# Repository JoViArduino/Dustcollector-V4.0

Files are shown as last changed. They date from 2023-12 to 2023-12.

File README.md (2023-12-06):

# Arduino Project: Dustcollector version 4 

Controlling dustcollecting system for multiple machines using valves. 

<p align="left" width="100%">
  
 

For every woodworker using lot of stationary machines it is important to remove the dust which is produced by using these machines. When one has many different machines, like table-saw, planer of a thicknesser one needs to connect all these machines. One needs to connect al these machies and includes valves so that only the dust of the machine which is used is collected. To achieve this one needs to include valves. This project allows you to install automatied valves which are controlled by Arduino''s. There is one Arduino for each manche. On them one and the same program can be installed. 
</p>


<br>
<sup> 
(The PCB for the project. An Arduino Uno is mounted under it while above there is an RS485 module. Here the PCB is placed on a test print of housing. Note the housing is only printer partially here, to see whether the PCB fits.)
</sup>

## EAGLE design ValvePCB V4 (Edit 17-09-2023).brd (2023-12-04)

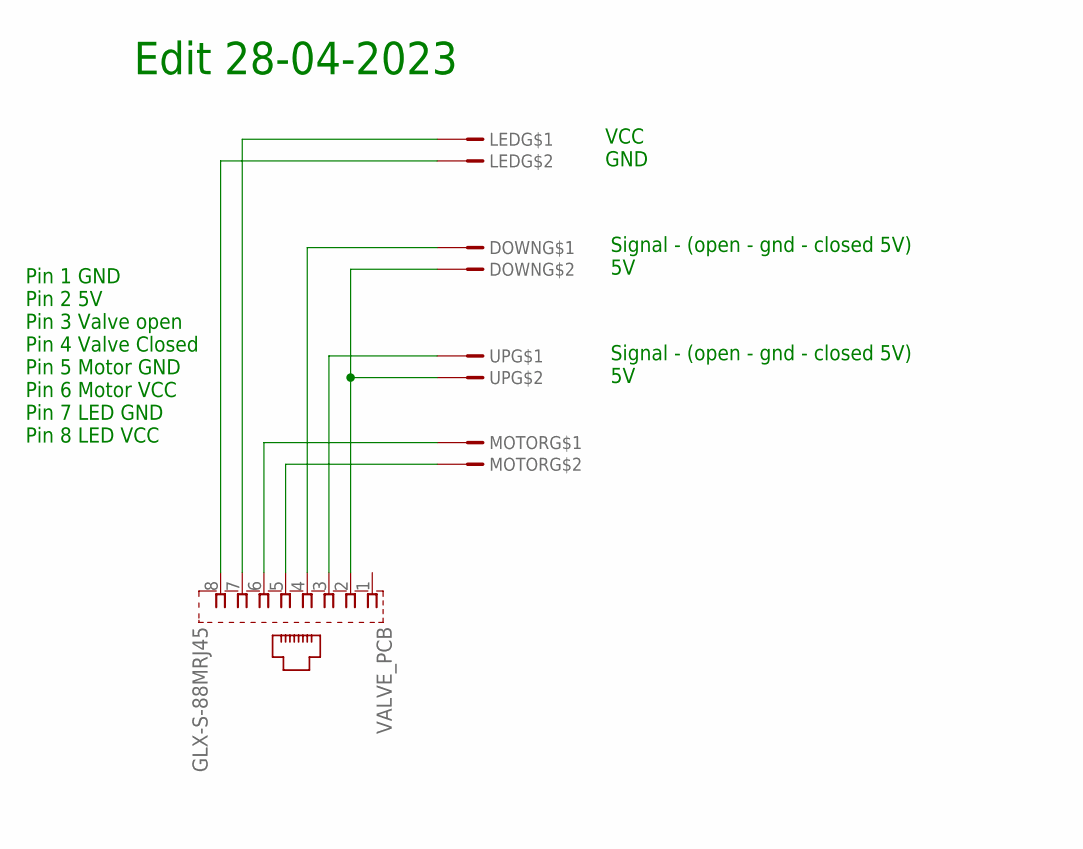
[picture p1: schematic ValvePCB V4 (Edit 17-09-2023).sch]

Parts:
DOWN: JST2; HDRV2W64P254_1X2_712X508X838B
LED: JST2; HDRV2W64P254_1X2_712X508X838B
MOTOR: JST2; HDRV2W64P254_1X2_712X508X838B
UP: JST2; HDRV2W64P254_1X2_712X508X838B
VALVE_PCB: GLX-S-88MRJ45; GLX-S-88M

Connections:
unnamed: MOTOR.1, VALVE_PCB.6
unnamed: MOTOR.2, VALVE_PCB.5
unnamed: UP.1, VALVE_PCB.3
unnamed: DOWN.2, UP.2, VALVE_PCB.2
unnamed: DOWN.1, VALVE_PCB.4
unnamed: LED.2, VALVE_PCB.8
unnamed: LED.1, VALVE_PCB.7

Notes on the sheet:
Pin 1 GND Pin 2 5V Pin 3 Valve open Pin 4 Valve Closed Pin 5 Motor GND Pin 6 Motor VCC Pin 7 LED GND Pin 8 LED VCC
Edit 28-04-2023
Signal - (open - gnd - closed 5V) 5V
VCC GND

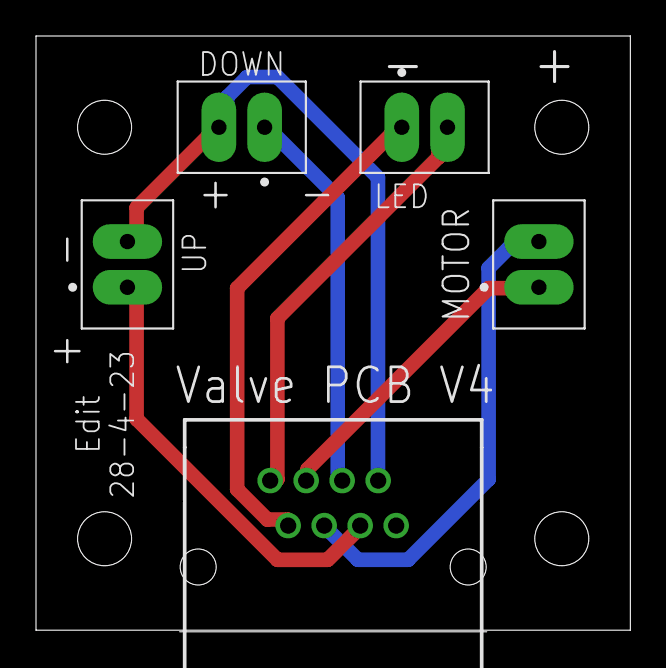
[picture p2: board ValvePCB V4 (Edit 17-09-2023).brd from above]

Board: 2 copper layers, 33.0 x 33.0 mm, 5 parts (0 on the bottom side), 7 nets.

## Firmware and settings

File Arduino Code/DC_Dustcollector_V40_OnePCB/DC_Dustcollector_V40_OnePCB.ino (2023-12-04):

//---------------------------------------------------------------------------------------------
// Dustcollector V4.0
//---------------------------------------------------------------------------------------------
//
// WARNING!!!!!!!!!!!!!!!!!!
// THIS VERSION is for dustcollector using one PCB....
// it cannot be used on the older version, which uses different pcb's... pinout is different!!!
// They are however compatible!!!!! ---> V3.1 25-11-2023!!!!
//
//---------------------------------------------------------------------------------------------
//
// Name......: DC_Dustcollector_V32_OnePCB.ino
//
// Version...: V3.1 - 28-06-2023
// last edits: 14-02-2023
//           : 28-04-2023
//           : 17-05-2023 introducing tabs!!
//           : 21-05-2023 resistor pulling Emergency low...
//           : 26-05-2023 Made some minor changes...
//           : 31-05-2023 Again some minor changes....
//           : 07-06-2023 Debugged DC Delay after restart and
//                        fixed bugs....
//           : 08-06-2023 Added response for Version All command!!
//           : 28-06-2023 Cleaning code .... minor fixes...
//           : 19-09-2023 Implementing functions for machines!!!
//           : 29-11-2023 Adjust functions to be used with one PCB
//                        and posility to reset all Arduino's remotly!!
// Author....: J. Vink
// Board.....: Arduino Uno
//
//---------------------------------------------------------------------------------------------
//
// See for description the Word document!! There is only one program for all Arduino's!!!!
//
//---------------------------------------------------------------------------------------------
//
// Changelog 20-04-2023
//
// Almost out of memory for variables (dynamic memory) ... so now using F( "...." ) within
// Sertial.print commands. This will store the text in the program storage space. Saved
// almost 30% ..............
//
// Changelog 28-04-2023:
//
// Discovered fault in the controller PCB. The three resistors are not connected to GND, ass they
// should be. Instead they are connected to the 5V line. So, when buttons are not pushed, the
// remain HIGH / 5V. The same holds for the resistors for the valves. They are also connected
// to %V instead of GND line.
//
// The PCB have been corrected and title have been given extra name (Edit 28-04-2023)!! These
// pcb's are ordered and this project assumes that these corrected pcb's will be used.
//
// Received PCB's from PCBWay ... so removed workarounds !!!!
//
// Changelog 21-05-2023:
//
// The Emergency line needs to bee pulled to GND. Otherwise it will float and randomly trigger
// emergency events. The Resister, 10K, needs to be soldered on one of the Arduino's. This
// will be the Arduino of the Dustcollector, as this one is always on. PCB for the
// controllers has been altered, so that a 10k resistor can be placed there, but for now
// it will be soldered on the Arduono of the Dustcollector!!!
//
// Tested this new settup .... does not work!!
//
// Changed Emergency pin from 13 to A3: This because this pin is connected to the onboard
// LED. Pulling the pin to ground therefore doesn not work!!
//
// New Pin A4 can be pulled low by 10k resistor. Pnly only one is needed... Added it
// to the Dustcollector controller!!
//
// Changelog 26-05-2023
//
// When installing the system discovered that for a stationary machines there was the need
// for an extra button. This button is connected to the handle with which the machine is
// operated. However all the lines are used. How to solve this problem?
//
// Solution: Use a separated box in which a Relais is switched using a deadman button
// (driven by 5V). This solves the need for another change to the PCB and leaves intact
// the possiblity of using a LEd for the power (not used at this moment).
//
// Changelog 31-05-2023
//
// Added functionality: All valves open of closed using serial. And when one valve is opened
// all others are closed. When one machine is turned of others are turned of.
//
// Changelog 03-06-2023
//
// Added the possibility to read the versions of all the connected controllers from the
// main controler!!
//
// Changelog 26-6-2023
//
// Cleaning the code....... etc etc etc.
//
// Changelog 19-9-2023
//
// Added functions for the machines / controller... some machines have build in switches
// so when these are used, we dont need a double function for the buttons in this project.
//
// Also change the check for the valves.. now first check is done after delay of 100ms!
//
//---------------------------------------------------------------------------------------------

#include <SPI.h>
#include <SoftwareSerial.h>
#include <EEPROM.h>

//---------------------------------------------------------------------------------------------
// When using serial monitor the version can be retrieved (command : Version). See below!
// This version is compatible with the latest veriosn ov V3.1, RESET is not available!!!
//---------------------------------------------------------------------------------------------

const String sVersion = "Version: V4.0 - 04-12-2023 (One PCB). ";

//------------------------------------------------------------------------------------------
// Pin defines: Note: Pins 0 and 1 not used because of usage of serial comms!!
//---------------------------------------------------------------------------------------------

#define EMERGENCY_Button_Pin  2 // Internal Emergency Button - 

//------------------------------------------
// Pins controling the communication
// between the Arduino's using the
// RS485 connection.
//------------------------------------------

#define TX_485_Pin            3 // Pin DI for the RS 485
#define RX_485_Pin            4 // Pin RO for the RS 485
#define RS485_control_Pin     5 // Pin DE / RE Enables or disables transmission and reception

#define Air_Button_BLUE_Pin   6
#define Air_Button_RED_Pin    7

//------------------------------------------
// Pins for controling relais for the valve.
// There are four relais used to control the
// polaritiy of the motor, in order rotate
// it clockwise or anticlockwise = moving
// the valve in a open or closed position.
//
// On the old many pcb version pin was this:
//
// #define Valve_Open1_Pin       8
// #define Valve_Open2_Pin       9
// #define Valve_Close1_Pin     10
// #define Valve_Close2_Pin     11
//------------------------------------------

#define Valve_Open_Pin        8
#define Valve_Close_Pin       9
#define Valve_Enabled_Pin    10

//------------------------------------------
// Pins for external emergency.
//------------------------------------------

#define RESET_Arduinos_Pin   11 // Reset all other Arduino's.

//------------------------------------------
// Pins for external emergency.
//------------------------------------------

#define EMERGENCY_Ext_Pin    12 // This is the line to the other Arduino's!!!

// Pins for the LED's.
#define LED_Motor_On_Pin     A0 // LED showing whether machine is on or off. 
#define LED_Air_On_Pin       A1 // LED showing whether dustcollector is on or off.
#define LED_Power_On_Pin     A2 // LED showing whether power is on or off (kind off stupid).

//------------------------------------------
// Pin for the Relais controling the machine.
// Using this pin as the old pin at start-up
// turned high, put on on the 220V line....
// Originaly this was pin 13. Pin 13 is connected
// to onboard LED, and will therefore will go
// into LOW state at start up, closing the
// relais and therefore start the motor.
// This problem will not occur with Analog
// pins...  so.... well....
//------------------------------------------

#define Machine_Power_Pin    A3 // Pin voor 220v relais controling power of motor!!

//------------------------------------------
// Pins for the contact switches of the airvalve.
//------------------------------------------

#define Valve_Status_Open    A4 // HIGH if switch is closed (it is NO = normally LOW)
#define Valve_Status_Closed  A5 // HIGh if switch is closed (it is NO = normally LOW)

//---------------------------------------------------------------------------------------------

#define RS485transmit HIGH
#define RS485receive  LOW

//------------------------------------------
// initiate the serial comm between the arduino's.
// This uses an external RX485 chip. THese
// can be used over longer distances.
//------------------------------------------

SoftwareSerial RS485_serial (RX_485_Pin , TX_485_Pin );

// Valve is controled by four relais. See above!!!
#define Valve_Relais_Moving  LOW    // Relais moving - current to valve, low opening, high closing
#define Valve_Relais_Idle    HIGH   // Relais idle - NO current to valve motor

#define Machine_Relais_Closed 1024  // Analog pin set to its maximum value.
#define Machine_Relais_Open   0     // Analog pin set to its lowest value.

// When emergency is raised, system requires reset...
boolean bEmergency_Raised            = false;
boolean bLeds_Emergency_On           = false;

boolean bShowDebugInfo               = false;

boolean bDust_Collector_Power_Status = false;
boolean bDustCollector_Power_On      = false;
boolean bDust_Collector_Restarting   = false;
boolean bMachine_Power_On            = false;

//------------------------------------------
// Delay for restarting the dustcollector
// Set this to 10000 = 12 seconds (appr).
//------------------------------------------

int iDust_Collecter_Restart_Counter = -1;
int iDust_Collecter_Restart_Delay_In_MilliSeconds = 10000;

//------------------------------------------
// If the valve is bissy (moving) we need
// to check whether it has reached one of
// its postions then stop the motor ASAP.
//------------------------------------------

boolean bValve_Relais_Bissy         = false;

//------------------------------------------
// If Valve is moving, then this is used for the
// direction! Opening = true, Closing = false.
//------------------------------------------

boolean bValve_Relais_Opening       = false;

//------------------------------------------
// Actions - (commands and responses)
// These are transmitted via the RS485 line.
//------------------------------------------

int iAction_Dust_Collector_On       = 1;
int iAction_Dust_Collector_Off      = 2;

int iAction_Machine_On              = 11;
int iAction_Machine_Off             = 12;

int iAction_Machine_All_Off         = 13;
int iAction_Machine_All_Others_Off  = 14;

int iAction_Status_Machine_On       = 15;
int iAction_Status_Machine_Off      = 16;

int iAction_Gate_Valve_Open_All     = 21;
int iAction_Gate_Valve_Close_All    = 22;
int iAction_Gate_Valve_Open_Others  = 23;
int iAction_Gate_Valve_Close_Others = 24;

int iAction_Request_ValveStatus     = 31;
int iAction_Status_ValveOpen        = 32;
int iAction_Status_ValveClosed      = 33;
int iAction_Status_ValveMoving      = 34;

int iAction_Project_Get_Version     = 41;
int iAction_Project_Version_Info    = 42;

int iAction_Request_Status          = 81;
int iAction_Status_Ready            = 82;

int iAction_Set_IDNumber            = 83;
int iAction_Set_MaxMachines         = 84;

int iAction_IDNumber_SetOk          = 85;
int iAction_MaxMachines_SetOk       = 86;

int iAction_IDNumber_SetFailed      = 87;
int iAction_MaxMachines_SetFailed   = 88;

int iAction_Emergency_Off           = 90;
int iAction_Emergency               = 99;

//------------------------------------------
// Controller variables stored in EEPROM
//
// There is another variable which can be
// stored in EEPROM memory See Above!!!
//
// WARNING: Dustcollector ID_Number must
// be 1 and equal to iID_DustCollector!!!
//------------------------------------------

int iID_DustCollector = 1; // Dont edit this number!!!

int iID_Number   = 99;     // It can be changed using Serial monitor - IDNumber x (where 0 < x < 64)!
// here 99 is used for a standard. If the Arduino already contains a
// IDNumber then this is used.. So, 99 means that this Arduino IDNumber must
// be set!!!
// Each Arduino must have an unique ID#!!

int iMaxMachines = 10;     // It can be changed using Serial monitor - Max x (where 0 < x < 64)!

int iID_Function = 0;      // Number for the funciton of the machine!
// 0 = Normal function (Default).
// 1 = Only air.

int iRSDelay = 2;          // Delay for the read and write to the RS485!
// 1 = 9600 baud
// 2 = 4800 baud etc

//------------------------------------------
// Variable showing whether any connected
// controllers are active.
//------------------------------------------

int iNumber_Controllers_Active = 0;

//---------------------------------------------------------------------------------------------
// Setup routine to initialise pins etc.
//---------------------------------------------------------------------------------------------
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
void loop()
{
  //------------------------------------------
  // Handle serial comm
  // See Z_DC_SerialFunctions.ino!!!
  //------------------------------------------

  Sub_Handle_Serial();

  //------------------------------------------
  // Handle communication between arduino's
  // via RS485 Line!
  // See Z_DC_FunctionsRS485.ino!!!
  //------------------------------------------

  Sub_Handle_RS485_Serial();

  //------------------------------------------
  // Handle Button presses - emergency line
  //------------------------------------------

  if ( digitalRead( EMERGENCY_Button_Pin ) && (!bEmergency_Raised))
  {
    Emergency_Routine();
  }

  //------------------------------------------
  // Handle Button presses
  //------------------------------------------

  if ( digitalRead( EMERGENCY_Ext_Pin ) && (!bEmergency_Raised))
  {
    Emergency_External_Routine();
  }

  //------------------------------------------
  // Handle Button presses - blue button
  //------------------------------------------

  if ( digitalRead( Air_Button_BLUE_Pin )  && (!bEmergency_Raised) && (!digitalRead( Air_Button_RED_Pin )) )
  {

    if (iID_Number == iID_DustCollector)
    {
      Sub_Handle_Blue_Button_Press_Dust_Collector();
    }
    else
    {
      Sub_Handle_Blue_Button_Press_Machine();
    }

  }

  //------------------------------------------
  // Handle Button presses - red button
  //------------------------------------------

  if ( digitalRead( Air_Button_RED_Pin )  && (!bEmergency_Raised) && (!digitalRead(Air_Button_BLUE_Pin)) )
  {
    if (iID_Number == iID_DustCollector)
    {
      Sub_Handle_Red_Button_Press_Dust_Collector();
    }
    else
    {
      Sub_Handle_Red_Button_Press_Machine();
    }
  }

  //------------------------------------------
  // Handle button presses - Reset!
  //------------------------------------------

  if ( digitalRead( Air_Button_RED_Pin ) && digitalRead( Air_Button_BLUE_Pin ) && (bEmergency_Raised))
  {
    Sub_RS485_WriteString( iID_Number , iID_DustCollector , iAction_Emergency_Off , 0 );
    bEmergency_Raised = false;
    analogWrite( LED_Motor_On_Pin , 0 );
    analogWrite( LED_Air_On_Pin   , 0 );
    delay(1000);
  }

  //------------------------------------------
  // Delay to make sure that RS485 is ready!
  //------------------------------------------

  delay(10);

  //------------------------------------------
  // Check whether the Dustcollector is set
  // for a restart! If so, then the Restart
  // delay is greater then 0! Count down
  // and then if check if counter has
  // come to zere or below. If so, turn
  // on Dustcollector
  //------------------------------------------

  if (iDust_Collecter_Restart_Counter >= 1  )
  {
    iDust_Collecter_Restart_Counter -= 10;

    if ((  bDust_Collector_Restarting  ) && (iID_Number == iID_DustCollector) )
    {
      // Assume that the Loop takes appr 10ms
      Sub_DustCollector_Control( true );
    }
  }

  //------------------------------------------
  // The Valve may still be opening or closing.
  // Check whether it has reached its open
  // or closed position. If it has then
  // stop the motor!!
  //------------------------------------------

  Check_Valve_Movement();

  //------------------------------------------
  // if emergency is raised, blink
  // the Air and Power LED's.
  //------------------------------------------

  if ( bEmergency_Raised )
  {
    if (bLeds_Emergency_On)
    {
      bLeds_Emergency_On = false;
      analogWrite( LED_Motor_On_Pin , 0 );
      analogWrite( LED_Air_On_Pin   , 1023 );
    }
    else
    {
      bLeds_Emergency_On = true;
      analogWrite( LED_Motor_On_Pin , 1023 );
      analogWrite( LED_Air_On_Pin   , 0 );
    }
    delay(100);
  }

} // End Sub

//---------------------------------------------------------------------------------------------
// Sub_Handle_Blue_Button_Press_Dust_Collector() routine
//---------------------------------------------------------------------------------------------

void Sub_Handle_Blue_Button_Press_Dust_Collector()
{

  if (!bDustCollector_Power_On)
  {
    // Send button press info to Serial
    Serial.println(F( "Blue Air Button pressed. Turning on Dustcollector..."));

    // Open the valve connected to this machine.
    Sub_Valve_Control( true );

    // Send button press to RS485 line
    Sub_RS485_WriteString( iID_Number , iID_DustCollector , iAction_Dust_Collector_On , 0 );

    bDustCollector_Power_On = true;

    //------------------------------------------
    // If button is pressed longer then 900ms
    // then also turn on the machine itself. If
    // the button is no longer pressed then
    // do nothin further.
    //------------------------------------------

    delay( 300 );
    Check_Valve_Movement(); // See below!!
    Serial.println( F( "Holding blue button..") );

    if ( digitalRead( Air_Button_BLUE_Pin ) )
    { delay( 300 );
      Check_Valve_Movement();
      Serial.println( F( "Holding ..") );
      if ( digitalRead( Air_Button_BLUE_Pin ) )
      { delay(300);
        Check_Valve_Movement();
        Serial.println( F( "Holding .." ) );
      }
    }
  }

  if ( digitalRead( Air_Button_BLUE_Pin )  && (!bEmergency_Raised))
  {
    Serial.println( F( "Blue Air Button pressed long or second time, so turn on Machine" ) );
    bMachine_Power_On = true;
    Sub_Machine_Control( true );
    // Let the controller of the Dustcollector know that machine is turned on!!
    Sub_RS485_WriteString( iID_Number , iID_DustCollector , iAction_Machine_On , 0 );
    delay( 300 );
  }
}

//---------------------------------------------------------------------------------------------
//---------------------------------------------------------------------------------------------
//---------------------------------------------------------------------------------------------
//
// WORK IN PROGRESS
//
// Button press must be handled differently for dustcollector controller and machines
//
// NOT DONE YET.... both functions are still the same!!!
//
// Rewrite and combine shared code ...
//
//---------------------------------------------------------------------------------------------
//---------------------------------------------------------------------------------------------
//---------------------------------------------------------------------------------------------

//---------------------------------------------------------------------------------------------
// Sub_Handle_Blue_Button_Press_Machine() routine
//---------------------------------------------------------------------------------------------

void Sub_Handle_Blue_Button_Press_Machine()
{

  //------------------------------------------
  // If Function of the machine is such that
  // it has its own power button then leave
  // this function... Because machine is
  // controlled by its own power button!!!
  //------------------------------------------

  if (iID_Function == 1)
  {
    exit;
  }

  if (!bDustCollector_Power_On)
  {
    // Send button press info to Serial
    Serial.println(F( "Blue Air Button pressed. Turning on Dustcollector..."));

    // Open the valve connected to this machine.
    Sub_Valve_Control( true );

    analogWrite( LED_Air_On_Pin   , 1023 ); // Turn LED just to be sure error not found even while debugging!!

    Check_Valve_Movement(); // See below!!

    // Send command press to RS485 line
    Sub_RS485_WriteString( iID_Number , iID_DustCollector , iAction_Dust_Collector_On , 0 );

    bDustCollector_Power_On = true;

    delay( 100 );
    Check_Valve_Movement(); // See below!!

    //------------------------------------------
    // If button is pressed longer then 900ms
    // then also turn on the machine itself. If
    // the button is no longer pressed then
    // do nothin further.
    //------------------------------------------

    delay( 200 );
    Check_Valve_Movement(); // See below!!

    if ( digitalRead( Air_Button_BLUE_Pin ) )
    { delay( 300 );
      Check_Valve_Movement();
      Serial.println( F( "Holding blue button ..") );
      if ( digitalRead( Air_Button_BLUE_Pin ) )
      { delay(300);
        Check_Valve_Movement();
        Serial.println( F( "Holding .." ) );
      }
    }
  }

  if ( digitalRead( Air_Button_BLUE_Pin )  && (!bEmergency_Raised))
  {
    Serial.println( F( "Blue Air Button pressed long or second time, so turn on Machine" ) );
    bMachine_Power_On = true;
    Sub_Machine_Control( true );
    // Let the controller of the Dustcollector know that machine is turned on!!
    Sub_RS485_WriteString( iID_Number , iID_DustCollector , iAction_Machine_On , 0 );
    delay( 300 );
  }
}
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

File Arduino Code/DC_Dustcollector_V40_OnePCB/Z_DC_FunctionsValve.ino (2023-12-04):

//---------------------------------------------------------------------------------------------
// Dustcollector V3.1
//---------------------------------------------------------------------------------------------
//
// Name......: Z_DC_FunctionsValve.ino
// Version...: 19-09-2023
//             Part of Dustcollector project V3.1
// last edits: 26-05-2023
// Author....: J. Vink
// Board.....: Arduino Uno
//
//---------------------------------------------------------------------------------------------

//---------------------------------------------------------------------------------------------
// Check_Valve_Movement() routine
//
// Checks whether the Valve is closed or opened. If so, then stop motor!!!
//
// There are two contactswitches which tunr high if the valve reaches one of its
// limits. To ensure that the motor is stopped as soon as it reaches such a position
// this funciton is called upon often (see DC_Dustcollector_V31.ino).
//---------------------------------------------------------------------------------------------

void Check_Valve_Movement()
{

  // If Valve is already in one of its positions
  // open or closed then do nothing, so return.
  if ( !bValve_Relais_Bissy )
  {
    return;
  }

  if ( ( ( digitalRead( Valve_Status_Open    ) == true) && (bValve_Relais_Opening)  ) ||
       ( ( digitalRead( Valve_Status_Closed  ) == true) && (!bValve_Relais_Opening) ) )
  {
    // Old code
    // digitalWrite( Valve_Open1_Pin  , Valve_Relais_Idle );
    // digitalWrite( Valve_Open2_Pin  , Valve_Relais_Idle );
    // digitalWrite( Valve_Close1_Pin , Valve_Relais_Idle );
    // digitalWrite( Valve_Close2_Pin , Valve_Relais_Idle );
    
    digitalWrite( Valve_Open_Pin  , Valve_Relais_Idle );
    digitalWrite( Valve_Close_Pin , Valve_Relais_Idle );
    
    bValve_Relais_Bissy = false;

    if ( digitalRead( Valve_Status_Open ) == true )
    {
      Serial.println( F( "Valve open, motor stopped ...." ) );
    }
    else
    {
      Serial.println( F( "Valve closed, motor stopped ...." ) );
    }
  }

}

//---------------------------------------------------------------------------------------------
// Sub_Valve_Control(bool bValve_Status) routine
//---------------------------------------------------------------------------------------------
//
// This procedure starts opening of closing the valve. This will take some time en the
// procedure will be finisched and retunr to the main loop, while the valve still moves.
// See the other funciton to check the status of the valve. Is it moving, or is it in
// one of its positions, open or closed. See Check_Valve_Movement() routine
//
// bValve_Direction true  = Open the valve
//                  false = Close the valve
//
// Two variables will be set:
//
// bValve_Relais_Opening true  = opening
//                       false = closing
//
// bValve_Relais_Bissy   true  = Valve motor running
//                       false = Valve motor not running
//
//---------------------------------------------------------------------------------------------

void Sub_Valve_Control( bool bValve_Direction )
{

  // just to make sure, open the relais (they should be open),
  // open here means Not Connected.
  // Old code
  // digitalWrite( Valve_Open1_Pin  , Valve_Relais_Idle );
  // digitalWrite( Valve_Open2_Pin  , Valve_Relais_Idle );
  // digitalWrite( Valve_Close1_Pin , Valve_Relais_Idle );
  // digitalWrite( Valve_Close2_Pin , Valve_Relais_Idle );
  
  digitalWrite( Valve_Open_Pin  , Valve_Relais_Idle );
  digitalWrite( Valve_Close_Pin , Valve_Relais_Idle );

  // If status = true then Valve must be opened
  if ( bValve_Direction == true )
  {
    digitalWrite( Valve_Open_Pin  , Valve_Relais_Moving );
    // digitalWrite( Valve_Open2_Pin  , Valve_Relais_Moving );
    analogWrite( LED_Air_On_Pin   , 1023 );
    bValve_Relais_Opening = true; // Set direction status, true is opening!
  }
  else
  {
    digitalWrite( Valve_Close_Pin , Valve_Relais_Moving );
    // digitalWrite( Valve_Close2_Pin , Valve_Relais_Moving );
    analogWrite( LED_Air_On_Pin   , 0 );
    bValve_Relais_Opening = false; // Set direction status!
  }

  bValve_Relais_Bissy = true;

  if ( bShowDebugInfo )
  {
    Serial.print( F( "Moving Valve: " ) );
    Serial.println( bValve_Relais_Opening );
  }

}

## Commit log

2023-12-04 Rename Arduino Shield V4 - Small - 7805 - REG - 25-11-2023.brd to Arduino Code /Arduino Shield V4 - Small - 7805 - REG - 25-11-2023.brd
    [Arduino Shield V4 - Small - 7805 - REG - 25-11-2023.brd]
2023-12-04 Update and rename DC_Dustcollector_V40_OnePCB.ino to Arduino Code/DC_Dustcollector_V40_OnePCB.ino
2023-12-04 Update and rename Arduino Code/DC_Dustcollector_V40_OnePCB.ino to Arduino Code/DC_Dustcollector_V40_OnePCB/DC_Dustcollector_V40_OnePCB.ino

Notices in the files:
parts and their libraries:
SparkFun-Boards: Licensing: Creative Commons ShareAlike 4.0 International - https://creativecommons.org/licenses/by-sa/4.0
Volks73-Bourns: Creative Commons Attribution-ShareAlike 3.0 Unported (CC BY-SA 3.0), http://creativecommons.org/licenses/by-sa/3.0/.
